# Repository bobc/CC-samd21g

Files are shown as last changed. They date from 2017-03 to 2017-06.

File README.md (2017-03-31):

CC-samd21g Breakout Board
========================================

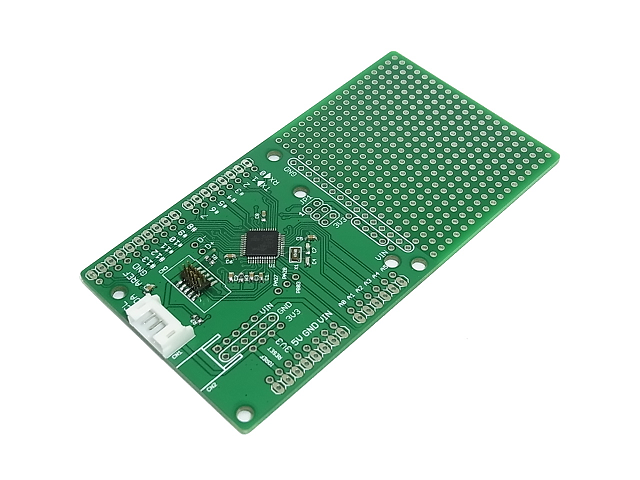
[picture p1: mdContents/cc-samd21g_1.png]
CC-SAMD21 Breakout
  
The CC-SAMD21 Breakout Board is breakout for the Atmel ATSAMD21G18 with prototyping area.  
This board shape is dirfferent from Arduino UNO or Zero, but it has Arduino Uno V3 style headers.  
There are only the minimal set of parts for running microcontroller. When you make your own circuit boards, this board might be helpful.

### Some highlights of the CC-samd21g Breakout Board:
 1. Main core: [ATSAMD21G18](http://www.atmel.com/devices/ATSAMD21G18A.aspx)
 2. Volatage regulator can be mounted in the extra prototyping area.
 3. Prototyping area 43.94mm(1730mil) x 53.34mm(2100mil)
 4. Measures 99.82mm(3930mil) x 53.34mm(2100mil)

Repository Contents
-------------------
* **/Hardware** - All Eagle design files (.brd, .sch)
* **/Software** - Software files for this hardware

Description(Pin Interfaces)
-------------------
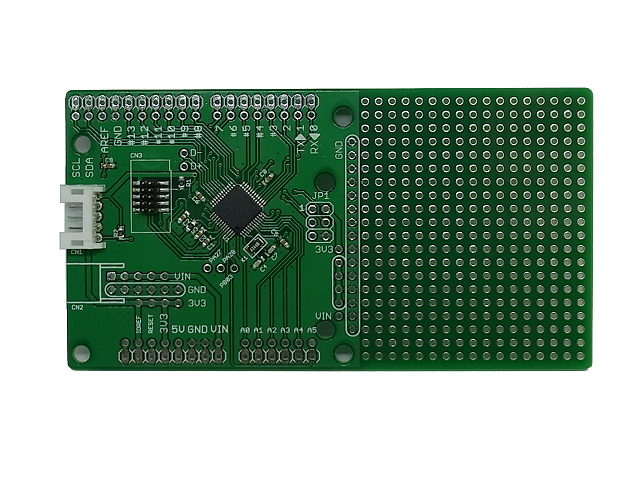
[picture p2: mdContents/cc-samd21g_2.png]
TopView


### CN1 Pin Descriptions:
This connector is for Flashing a program microcontroller.
If you change BOOT MODE, To be selected BOOT MODE before connecting the power supply.  
And also, Communicate with SMA21G using "Serial" function.
- **VCC:** Restrictly 3.3VDC.
- **TX:** PB22 used as UART TX.
- **RX:** PB23 used as UART RX.
- **GND:** GND.
- **BOOT MODE:** Connected to "PA13" H:Flash boot(normally) L:UART download

If you are interested in more useful uart module, please see the [General Serial Communication Board](https://github.com/NaoNaoMe/General-Serial-Communication-Board).

### CN2 Pin Descriptions:
This connector is as power supply.
You can mount a voltage regulator in the extra prototyping area near the connector.
- **VIN:** Depending on the voltage regulator requirements.
- **GND:** GND.

How to burn bootloader and upload sketch
-------------------
See [this page](BurnBootloader.md)

License
-------------------
The repository is released under [Creative Commons ShareAlike 4.0 International](https://creativecommons.org/licenses/by-sa/4.0/).

Distributed as-is; no warranty is given.

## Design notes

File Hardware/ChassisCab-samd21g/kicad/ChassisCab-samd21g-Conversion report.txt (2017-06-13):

info: Conversion report on 2017-06-13 19:33:48
info: 
info: Parameters:
info: Input  : C:\git_bobc\CC-samd21g\Hardware\ChassisCab-samd21g\ChassisCab-samd21g.brd
info: Output : C:\git_bobc\CC-samd21g\Hardware\ChassisCab-samd21g\kicad
info: 
info: Log:
info: Reading board file C:\git_bobc\CC-samd21g\Hardware\ChassisCab-samd21g\ChassisCab-samd21g.brd
info: Processing Library: arduino
info: Processing Library: jst
info: Processing Library: atmel
info: Processing Library: samtec
info: Processing Library: epson
info: Processing Library: rcl
info: Processing Library: Misc
warning: unsupported layer: 214 214bmp in 
warning: unsupported layer: 19 Unrouted in 
note: loose via converted to pad at 35.052,18.796 net=GND
note: loose via converted to pad at 25.4,22.86 net=GND
note: loose via converted to pad at 23.876,24.384 net=GND
note: loose via converted to pad at 21.336,26.924 net=GND
note: loose via converted to pad at 35.56,3.81 net=GND
note: loose via converted to pad at 38.1,3.81 net=GND
note: loose via converted to pad at 40.64,3.81 net=GND
note: loose via converted to pad at 43.18,3.81 net=GND
note: loose via converted to pad at 38.1,16.002 net=GND
note: loose via converted to pad at 40.64,17.78 net=GND
note: loose via converted to pad at 43.18,19.558 net=GND
note: loose via converted to pad at 40.64,41.148 net=GND
note: loose via converted to pad at 34.036,39.116 net=GND
note: loose via converted to pad at 33.02,42.164 net=GND
note: loose via converted to pad at 21.336,39.878 net=GND
note: loose via converted to pad at 11.176,38.862 net=GND
note: loose via converted to pad at 12.7,3.81 net=GND
note: loose via converted to pad at 15.24,3.81 net=GND
note: loose via converted to pad at 8.89,31.242 net=GND
note: loose via converted to pad at 3.302,27.686 net=GND
note: loose via converted to pad at 3.302,26.67 net=GND
note: loose via converted to pad at 10.414,32.766 net=GND
note: loose via converted to pad at 25.146,35.306 net=GND
note: loose via converted to pad at 32.004,23.876 net=GND
note: loose via converted to pad at 33.02,3.81 net=GND
note: loose via converted to pad at 43.434,29.972 net=GND
note: loose via converted to pad at 28.448,18.034 net=GND
note: loose via converted to pad at 10.414,23.622 net=GND
note: loose via converted to pad at 10.414,21.082 net=GND
note: loose via converted to pad at 5.842,15.24 net=GND
note: loose via converted to pad at 5.842,5.842 net=GND
note: loose via converted to pad at 10.414,9.398 net=GND
note: loose via converted to pad at 10.414,10.922 net=GND
note: loose via converted to pad at 11.938,10.922 net=GND
note: loose via converted to pad at 11.938,9.398 net=GND
note: loose via converted to pad at 3.556,49.53 net=GND
note: loose via converted to pad at 38.1,49.53 net=GND
note: loose via converted to pad at 27.178,50.8 net=GND
note: loose via converted to pad at 37.592,39.37 net=GND
note: loose via converted to pad at 3.302,36.322 net=GND
note: loose via converted to pad at 3.302,10.922 net=GND
note: loose via converted to pad at 12.446,48.26 net=SCK
note: loose via converted to pad at 52.07,22.86 net=+3V3
note: loose via converted to pad at 19.05,5.08 net=+3V3
note: loose via converted to pad at 13.97,12.7 net=+3V3
note: loose via converted to pad at 16.51,12.7 net=+3V3
note: loose via converted to pad at 19.05,12.7 net=+3V3
note: loose via converted to pad at 21.59,12.7 net=+3V3
note: loose via converted to pad at 13.97,5.08 net=+3V3
note: loose via converted to pad at 14.986,48.26 net=MISO
note: loose via converted to pad at 17.526,48.26 net=MOSI
note: loose via converted to pad at 20.066,48.26 net=SS
note: loose via converted to pad at 34.29,5.08 net=PA02_AIN0
note: loose via converted to pad at 7.366,48.26 net=PA03_AREFA
note: loose via converted to pad at 36.83,5.08 net=PB08_AIN2
note: loose via converted to pad at 39.37,5.08 net=PB09_AIN3
note: loose via converted to pad at 41.91,5.08 net=PA04_AIN4
note: loose via converted to pad at 44.45,5.08 net=PA05_AIN5
note: loose via converted to pad at 39.37,48.26 net=PA09_TCC0-W1
note: loose via converted to pad at 44.45,48.26 net=PA10_TCC0-W2
note: loose via converted to pad at 46.99,48.26 net=PA11_TCC0-W3
note: loose via converted to pad at 34.29,48.26 net=PA15_TCC0-W5
note: loose via converted to pad at 31.75,48.26 net=PA20_TCC0-W6
note: loose via converted to pad at 46.99,5.08 net=PB02_AIN10
note: loose via converted to pad at 29.21,48.26 net=PA21
note: loose via converted to pad at 22.606,48.26 net=PA07
note: loose via converted to pad at 4.826,48.26 net=SDA
note: loose via converted to pad at 2.286,48.26 net=SCL
note: loose via converted to pad at 16.51,5.08 net=SAMD21_RESET
note: loose via converted to pad at 41.91,48.26 net=PA08_TCC0-W0
note: loose via converted to pad at 36.83,48.26 net=PA14_TCC0-W4
note: loose via converted to pad at 25.146,48.26 net=PA06
note: loose via converted to pad at 11.43,17.78 net=VIN
note: loose via converted to pad at 13.97,17.78 net=VIN
note: loose via converted to pad at 16.51,17.78 net=VIN
note: loose via converted to pad at 19.05,17.78 net=VIN
note: loose via converted to pad at 52.07,10.16 net=VIN
note: loose via converted to pad at 29.21,5.08 net=VIN
note: loose via converted to pad at 52.07,20.32 net=N$900
note: loose via converted to pad at 52.07,17.78 net=N$900
note: loose via converted to pad at 52.07,15.24 net=N$900
note: loose via converted to pad at 52.07,12.7 net=N$900
note: loose via converted to pad at 57.15,50.8 net=N$3
note: loose via converted to pad at 57.15,48.26 net=N$4
note: loose via converted to pad at 57.15,45.72 net=N$5
note: loose via converted to pad at 57.15,43.18 net=N$6
note: loose via converted to pad at 57.15,40.64 net=N$7
note: loose via converted to pad at 57.15,38.1 net=N$8
note: loose via converted to pad at 57.15,35.56 net=N$9
note: loose via converted to pad at 57.15,33.02 net=N$10
note: loose via converted to pad at 57.15,30.48 net=N$11
note: loose via converted to pad at 57.15,27.94 net=N$12
note: loose via converted to pad at 57.15,25.4 net=N$13
note: loose via converted to pad at 57.15,22.86 net=N$14
note: loose via converted to pad at 57.15,20.32 net=N$15
note: loose via converted to pad at 57.15,17.78 net=N$16
note: loose via converted to pad at 57.15,15.24 net=N$17
note: loose via converted to pad at 57.15,12.7 net=N$18
note: loose via converted to pad at 57.15,10.16 net=N$19
note: loose via converted to pad at 57.15,7.62 net=N$20
note: loose via converted to pad at 57.15,5.08 net=N$21
note: loose via converted to pad at 57.15,2.54 net=N$22
note: loose via converted to pad at 59.69,50.8 net=N$23
note: loose via converted to pad at 59.69,48.26 net=N$24
note: loose via converted to pad at 59.69,45.72 net=N$25
note: loose via converted to pad at 59.69,43.18 net=N$26
note: loose via converted to pad at 59.69,40.64 net=N$27
note: loose via converted to pad at 59.69,38.1 net=N$28
note: loose via converted to pad at 59.69,35.56 net=N$29
note: loose via converted to pad at 59.69,33.02 net=N$30
note: loose via converted to pad at 59.69,30.48 net=N$31
note: loose via converted to pad at 59.69,27.94 net=N$32
note: loose via converted to pad at 59.69,25.4 net=N$33
note: loose via converted to pad at 59.69,22.86 net=N$34
note: loose via converted to pad at 59.69,20.32 net=N$35
note: loose via converted to pad at 59.69,17.78 net=N$36
note: loose via converted to pad at 59.69,15.24 net=N$37
note: loose via converted to pad at 59.69,12.7 net=N$38
note: loose via converted to pad at 59.69,10.16 net=N$39
note: loose via converted to pad at 59.69,7.62 net=N$40
note: loose via converted to pad at 59.69,5.08 net=N$41
note: loose via converted to pad at 59.69,2.54 net=N$42
note: loose via converted to pad at 62.23,50.8 net=N$43
note: loose via converted to pad at 62.23,48.26 net=N$44
note: loose via converted to pad at 62.23,45.72 net=N$45
note: loose via converted to pad at 62.23,43.18 net=N$46
note: loose via converted to pad at 62.23,40.64 net=N$47
note: loose via converted to pad at 62.23,38.1 net=N$48
note: loose via converted to pad at 62.23,35.56 net=N$49
note: loose via converted to pad at 62.23,33.02 net=N$50
note: loose via converted to pad at 62.23,30.48 net=N$51
note: loose via converted to pad at 62.23,27.94 net=N$52
note: loose via converted to pad at 62.23,25.4 net=N$53
note: loose via converted to pad at 62.23,22.86 net=N$54
note: loose via converted to pad at 62.23,20.32 net=N$55
note: loose via converted to pad at 62.23,17.78 net=N$56
note: loose via converted to pad at 62.23,15.24 net=N$57
note: loose via converted to pad at 62.23,12.7 net=N$58
note: loose via converted to pad at 62.23,10.16 net=N$59
note: loose via converted to pad at 62.23,7.62 net=N$60
note: loose via converted to pad at 62.23,5.08 net=N$61
note: loose via converted to pad at 62.23,2.54 net=N$62
note: loose via converted to pad at 64.77,50.8 net=N$63
note: loose via converted to pad at 64.77,48.26 net=N$64
note: loose via converted to pad at 64.77,45.72 net=N$65
note: loose via converted to pad at 64.77,43.18 net=N$66
note: loose via converted to pad at 64.77,40.64 net=N$67
note: loose via converted to pad at 64.77,38.1 net=N$68
note: loose via converted to pad at 64.77,35.56 net=N$69
note: loose via converted to pad at 64.77,33.02 net=N$70
note: loose via converted to pad at 64.77,30.48 net=N$71
note: loose via converted to pad at 64.77,27.94 net=N$72
note: loose via converted to pad at 64.77,25.4 net=N$73
note: loose via converted to pad at 64.77,22.86 net=N$74
note: loose via converted to pad at 64.77,20.32 net=N$75
note: loose via converted to pad at 64.77,17.78 net=N$76
note: loose via converted to pad at 64.77,15.24 net=N$77
note: loose via converted to pad at 64.77,12.7 net=N$78
note: loose via converted to pad at 64.77,10.16 net=N$79
note: loose via converted to pad at 64.77,7.62 net=N$80
note: loose via converted to pad at 64.77,5.08 net=N$81
note: loose via converted to pad at 64.77,2.54 net=N$82
note: loose via converted to pad at 67.31,50.8 net=N$83
note: loose via converted to pad at 67.31,48.26 net=N$84
note: loose via converted to pad at 67.31,45.72 net=N$85
note: loose via converted to pad at 67.31,43.18 net=N$86
note: loose via converted to pad at 67.31,40.64 net=N$87
note: loose via converted to pad at 67.31,38.1 net=N$88
note: loose via converted to pad at 67.31,35.56 net=N$89
note: loose via converted to pad at 67.31,33.02 net=N$90
note: loose via converted to pad at 67.31,30.48 net=N$91
note: loose via converted to pad at 67.31,27.94 net=N$92
note: loose via converted to pad at 67.31,25.4 net=N$93
note: loose via converted to pad at 67.31,22.86 net=N$94
note: loose via converted to pad at 67.31,20.32 net=N$95
note: loose via converted to pad at 67.31,17.78 net=N$96
note: loose via converted to pad at 67.31,15.24 net=N$97
note: loose via converted to pad at 67.31,12.7 net=N$98
note: loose via converted to pad at 67.31,10.16 net=N$99
note: loose via converted to pad at 67.31,7.62 net=N$100
note: loose via converted to pad at 67.31,5.08 net=N$101
note: loose via converted to pad at 67.31,2.54 net=N$102
note: loose via converted to pad at 69.85,50.8 net=N$103
note: loose via converted to pad at 69.85,48.26 net=N$104
note: loose via converted to pad at 69.85,45.72 net=N$105
note: loose via converted to pad at 69.85,43.18 net=N$106
note: loose via converted to pad at 69.85,40.64 net=N$107
note: loose via converted to pad at 69.85,38.1 net=N$108
note: loose via converted to pad at 69.85,35.56 net=N$109
note: loose via converted to pad at 69.85,33.02 net=N$110
note: loose via converted to pad at 69.85,30.48 net=N$111
note: loose via converted to pad at 69.85,27.94 net=N$112
note: loose via converted to pad at 69.85,25.4 net=N$113
note: loose via converted to pad at 69.85,22.86 net=N$114
note: loose via converted to pad at 69.85,20.32 net=N$115
note: loose via converted to pad at 69.85,17.78 net=N$116
note: loose via converted to pad at 69.85,15.24 net=N$117
note: loose via converted to pad at 69.85,12.7 net=N$118
note: loose via converted to pad at 69.85,10.16 net=N$119
note: loose via converted to pad at 69.85,7.62 net=N$120
note: loose via converted to pad at 69.85,5.08 net=N$121
note: loose via converted to pad at 69.85,2.54 net=N$122
note: loose via converted to pad at 72.39,50.8 net=N$123
note: loose via converted to pad at 72.39,48.26 net=N$124
note: loose via converted to pad at 72.39,45.72 net=N$125
note: loose via converted to pad at 72.39,43.18 net=N$126
note: loose via converted to pad at 72.39,40.64 net=N$127
note: loose via converted to pad at 72.39,38.1 net=N$128
note: loose via converted to pad at 72.39,35.56 net=N$129
note: loose via converted to pad at 72.39,33.02 net=N$130
note: loose via converted to pad at 72.39,30.48 net=N$131
note: loose via converted to pad at 72.39,27.94 net=N$132
note: loose via converted to pad at 72.39,25.4 net=N$133
note: loose via converted to pad at 72.39,22.86 net=N$134
note: loose via converted to pad at 72.39,20.32 net=N$135
note: loose via converted to pad at 72.39,17.78 net=N$136
note: loose via converted to pad at 72.39,15.24 net=N$137
note: loose via converted to pad at 72.39,12.7 net=N$138
note: loose via converted to pad at 72.39,10.16 net=N$139
note: loose via converted to pad at 72.39,7.62 net=N$140
note: loose via converted to pad at 72.39,5.08 net=N$141
note: loose via converted to pad at 72.39,2.54 net=N$142
note: loose via converted to pad at 74.93,50.8 net=N$143
note: loose via converted to pad at 74.93,48.26 net=N$144
note: loose via converted to pad at 74.93,45.72 net=N$145
note: loose via converted to pad at 74.93,43.18 net=N$146
note: loose via converted to pad at 74.93,40.64 net=N$147
note: loose via converted to pad at 74.93,38.1 net=N$148
note: loose via converted to pad at 74.93,35.56 net=N$149
note: loose via converted to pad at 74.93,33.02 net=N$150
note: loose via converted to pad at 74.93,30.48 net=N$151
note: loose via converted to pad at 74.93,27.94 net=N$152
note: loose via converted to pad at 74.93,25.4 net=N$153
note: loose via converted to pad at 74.93,22.86 net=N$154
note: loose via converted to pad at 74.93,20.32 net=N$155
note: loose via converted to pad at 74.93,17.78 net=N$156
note: loose via converted to pad at 74.93,15.24 net=N$157
note: loose via converted to pad at 74.93,12.7 net=N$158
note: loose via converted to pad at 74.93,10.16 net=N$159
note: loose via converted to pad at 74.93,7.62 net=N$160
note: loose via converted to pad at 74.93,5.08 net=N$161
note: loose via converted to pad at 74.93,2.54 net=N$162
note: loose via converted to pad at 77.47,50.8 net=N$163
note: loose via converted to pad at 77.47,48.26 net=N$164
note: loose via converted to pad at 77.47,45.72 net=N$165
note: loose via converted to pad at 77.47,43.18 net=N$166
note: loose via converted to pad at 77.47,40.64 net=N$167
note: loose via converted to pad at 77.47,38.1 net=N$168
note: loose via converted to pad at 77.47,35.56 net=N$169
note: loose via converted to pad at 77.47,33.02 net=N$170
note: loose via converted to pad at 77.47,30.48 net=N$171
note: loose via converted to pad at 77.47,27.94 net=N$172
note: loose via converted to pad at 77.47,25.4 net=N$173
note: loose via converted to pad at 77.47,22.86 net=N$174
note: loose via converted to pad at 77.47,20.32 net=N$175
note: loose via converted to pad at 77.47,17.78 net=N$176
note: loose via converted to pad at 77.47,15.24 net=N$177
note: loose via converted to pad at 77.47,12.7 net=N$178
note: loose via converted to pad at 77.47,10.16 net=N$179
note: loose via converted to pad at 77.47,7.62 net=N$180
note: loose via converted to pad at 77.47,5.08 net=N$181
note: loose via converted to pad at 77.47,2.54 net=N$182
note: loose via converted to pad at 80.01,50.8 net=N$183
note: loose via converted to pad at 80.01,48.26 net=N$184
note: loose via converted to pad at 80.01,45.72 net=N$185
note: loose via converted to pad at 80.01,43.18 net=N$186
note: loose via converted to pad at 80.01,40.64 net=N$187
note: loose via converted to pad at 80.01,38.1 net=N$188
note: loose via converted to pad at 80.01,35.56 net=N$189
note: loose via converted to pad at 80.01,33.02 net=N$190
note: loose via converted to pad at 80.01,30.48 net=N$191
note: loose via converted to pad at 80.01,27.94 net=N$192
note: loose via converted to pad at 80.01,25.4 net=N$193
note: loose via converted to pad at 80.01,22.86 net=N$194
note: loose via converted to pad at 80.01,20.32 net=N$195
note: loose via converted to pad at 80.01,17.78 net=N$196
note: loose via converted to pad at 80.01,15.24 net=N$197
note: loose via converted to pad at 80.01,12.7 net=N$198
note: loose via converted to pad at 80.01,10.16 net=N$199
note: loose via converted to pad at 80.01,7.62 net=N$200
note: loose via converted to pad at 80.01,5.08 net=N$201
note: loose via converted to pad at 80.01,2.54 net=N$202
note: loose via converted to pad at 82.55,50.8 net=N$203
note: loose via converted to pad at 82.55,48.26 net=N$204
note: loose via converted to pad at 82.55,45.72 net=N$205
note: loose via converted to pad at 82.55,43.18 net=N$206
note: loose via converted to pad at 82.55,40.64 net=N$207
note: loose via converted to pad at 82.55,38.1 net=N$208
note: loose via converted to pad at 82.55,35.56 net=N$209
note: loose via converted to pad at 82.55,33.02 net=N$210
note: loose via converted to pad at 82.55,30.48 net=N$211
note: loose via converted to pad at 82.55,27.94 net=N$212
note: loose via converted to pad at 82.55,25.4 net=N$213
note: loose via converted to pad at 82.55,22.86 net=N$214
note: loose via converted to pad at 82.55,20.32 net=N$215
note: loose via converted to pad at 82.55,17.78 net=N$216
note: loose via converted to pad at 82.55,15.24 net=N$217
note: loose via converted to pad at 82.55,12.7 net=N$218
note: loose via converted to pad at 82.55,10.16 net=N$219
note: loose via converted to pad at 82.55,7.62 net=N$220
note: loose via converted to pad at 82.55,5.08 net=N$221
note: loose via converted to pad at 82.55,2.54 net=N$222
note: loose via converted to pad at 85.09,50.8 net=N$223
note: loose via converted to pad at 85.09,48.26 net=N$224
note: loose via converted to pad at 85.09,45.72 net=N$225
note: loose via converted to pad at 85.09,43.18 net=N$226
note: loose via converted to pad at 85.09,40.64 net=N$227
note: loose via converted to pad at 85.09,38.1 net=N$228
note: loose via converted to pad at 85.09,35.56 net=N$229
note: loose via converted to pad at 85.09,33.02 net=N$230
note: loose via converted to pad at 85.09,30.48 net=N$231
note: loose via converted to pad at 85.09,27.94 net=N$232
note: loose via converted to pad at 85.09,25.4 net=N$233
note: loose via converted to pad at 85.09,22.86 net=N$234
note: loose via converted to pad at 85.09,20.32 net=N$235
note: loose via converted to pad at 85.09,17.78 net=N$236
note: loose via converted to pad at 85.09,15.24 net=N$237
note: loose via converted to pad at 85.09,12.7 net=N$238
note: loose via converted to pad at 85.09,10.16 net=N$239
note: loose via converted to pad at 85.09,7.62 net=N$240
note: loose via converted to pad at 85.09,5.08 net=N$241
note: loose via converted to pad at 85.09,2.54 net=N$242
note: loose via converted to pad at 87.63,50.8 net=N$243
note: loose via converted to pad at 87.63,48.26 net=N$244
note: loose via converted to pad at 87.63,45.72 net=N$245
note: loose via converted to pad at 87.63,43.18 net=N$246
note: loose via converted to pad at 87.63,40.64 net=N$247
note: loose via converted to pad at 87.63,38.1 net=N$248
note: loose via converted to pad at 87.63,35.56 net=N$249
note: loose via converted to pad at 87.63,33.02 net=N$250
note: loose via converted to pad at 87.63,30.48 net=N$251
note: loose via converted to pad at 87.63,27.94 net=N$252
note: loose via converted to pad at 87.63,25.4 net=N$253
note: loose via converted to pad at 87.63,22.86 net=N$254
note: loose via converted to pad at 87.63,20.32 net=N$255
note: loose via converted to pad at 87.63,17.78 net=N$256
note: loose via converted to pad at 87.63,15.24 net=N$257
note: loose via converted to pad at 87.63,12.7 net=N$258
note: loose via converted to pad at 87.63,10.16 net=N$259
note: loose via converted to pad at 87.63,7.62 net=N$260
note: loose via converted to pad at 87.63,5.08 net=N$261
note: loose via converted to pad at 87.63,2.54 net=N$262
note: loose via converted to pad at 90.17,50.8 net=N$263
note: loose via converted to pad at 90.17,48.26 net=N$264
note: loose via converted to pad at 90.17,45.72 net=N$265
note: loose via converted to pad at 90.17,43.18 net=N$266
note: loose via converted to pad at 90.17,40.64 net=N$267
note: loose via converted to pad at 90.17,38.1 net=N$268
note: loose via converted to pad at 90.17,35.56 net=N$269
note: loose via converted to pad at 90.17,33.02 net=N$270
note: loose via converted to pad at 90.17,30.48 net=N$271
note: loose via converted to pad at 90.17,27.94 net=N$272
note: loose via converted to pad at 90.17,25.4 net=N$273
note: loose via converted to pad at 90.17,22.86 net=N$274
note: loose via converted to pad at 90.17,20.32 net=N$275
note: loose via converted to pad at 90.17,17.78 net=N$276
note: loose via converted to pad at 90.17,15.24 net=N$277
note: loose via converted to pad at 90.17,12.7 net=N$278
note: loose via converted to pad at 90.17,10.16 net=N$279
note: loose via converted to pad at 90.17,7.62 net=N$280
note: loose via converted to pad at 90.17,5.08 net=N$281
note: loose via converted to pad at 90.17,2.54 net=N$282
note: loose via converted to pad at 92.71,50.8 net=N$283
note: loose via converted to pad at 92.71,48.26 net=N$284
note: loose via converted to pad at 92.71,45.72 net=N$285
note: loose via converted to pad at 92.71,43.18 net=N$286
note: loose via converted to pad at 92.71,40.64 net=N$287
note: loose via converted to pad at 92.71,38.1 net=N$288
note: loose via converted to pad at 92.71,35.56 net=N$289
note: loose via converted to pad at 92.71,33.02 net=N$290
note: loose via converted to pad at 92.71,30.48 net=N$291
note: loose via converted to pad at 92.71,27.94 net=N$292
note: loose via converted to pad at 92.71,25.4 net=N$293
note: loose via converted to pad at 92.71,22.86 net=N$294
note: loose via converted to pad at 92.71,20.32 net=N$295
note: loose via converted to pad at 92.71,17.78 net=N$296
note: loose via converted to pad at 92.71,15.24 net=N$297
note: loose via converted to pad at 92.71,12.7 net=N$298
note: loose via converted to pad at 92.71,10.16 net=N$299
note: loose via converted to pad at 92.71,7.62 net=N$300
note: loose via converted to pad at 92.71,5.08 net=N$301
note: loose via converted to pad at 92.71,2.54 net=N$302
note: loose via converted to pad at 95.25,50.8 net=N$303
note: loose via converted to pad at 95.25,48.26 net=N$304
note: loose via converted to pad at 95.25,45.72 net=N$305
note: loose via converted to pad at 95.25,43.18 net=N$306
note: loose via converted to pad at 95.25,40.64 net=N$307
note: loose via converted to pad at 95.25,38.1 net=N$308
note: loose via converted to pad at 95.25,35.56 net=N$309
note: loose via converted to pad at 95.25,33.02 net=N$310
note: loose via converted to pad at 95.25,30.48 net=N$311
note: loose via converted to pad at 95.25,27.94 net=N$312
note: loose via converted to pad at 95.25,25.4 net=N$313
note: loose via converted to pad at 95.25,22.86 net=N$314
note: loose via converted to pad at 95.25,20.32 net=N$315
note: loose via converted to pad at 95.25,17.78 net=N$316
note: loose via converted to pad at 95.25,15.24 net=N$317
note: loose via converted to pad at 95.25,12.7 net=N$318
note: loose via converted to pad at 95.25,10.16 net=N$319
note: loose via converted to pad at 95.25,7.62 net=N$320
note: loose via converted to pad at 95.25,5.08 net=N$321
note: loose via converted to pad at 95.25,2.54 net=N$322
note: loose via converted to pad at 97.79,50.8 net=N$323
note: loose via converted to pad at 97.79,48.26 net=N$324
note: loose via converted to pad at 97.79,45.72 net=N$325
note: loose via converted to pad at 97.79,43.18 net=N$326
note: loose via converted to pad at 97.79,40.64 net=N$327
note: loose via converted to pad at 97.79,38.1 net=N$328
note: loose via converted to pad at 97.79,35.56 net=N$329
note: loose via converted to pad at 97.79,33.02 net=N$330
note: loose via converted to pad at 97.79,30.48 net=N$331
note: loose via converted to pad at 97.79,27.94 net=N$332
note: loose via converted to pad at 97.79,25.4 net=N$333
note: loose via converted to pad at 97.79,22.86 net=N$334
note: loose via converted to pad at 97.79,20.32 net=N$335
note: loose via converted to pad at 97.79,17.78 net=N$336
note: loose via converted to pad at 97.79,15.24 net=N$337
note: loose via converted to pad at 97.79,12.7 net=N$338
note: loose via converted to pad at 97.79,10.16 net=N$339
note: loose via converted to pad at 97.79,7.62 net=N$340
note: loose via converted to pad at 97.79,5.08 net=N$341
note: loose via converted to pad at 97.79,2.54 net=N$342
info: Writing board C:\git_bobc\CC-samd21g\Hardware\ChassisCab-samd21g\kicad\ChassisCab-samd21g.kicad_pcb
info: Reading schematic file C:\git_bobc\CC-samd21g\Hardware\ChassisCab-samd21g\ChassisCab-samd21g.sch
info: Processing Library: Misc
info: Processing Library: arduino
note: 1X10/90 is renamed to 1X10_90
info: Processing Library: jst
info: Processing Library: atmel
info: Processing Library: samtec
info: Processing Library: epson
info: Processing Library: rcl
note: 0204/5 is renamed to 0204_5
note: 0204/7 is renamed to 0204_7
note: 0207/10 is renamed to 0207_10
note: 0207/12 is renamed to 0207_12
note: 0207/15 is renamed to 0207_15
note: 0207/2V is renamed to 0207_2V
note: 0207/5V is renamed to 0207_5V
note: 0207/7 is renamed to 0207_7
note: 0309/10 is renamed to 0309_10
note: 0309/12 is renamed to 0309_12
note: 0411/12 is renamed to 0411_12
note: 0411/15 is renamed to 0411_15
note: 0414/15 is renamed to 0414_15
note: 0617/17 is renamed to 0617_17
note: 0617/22 is renamed to 0617_22
note: 0922/22 is renamed to 0922_22
note: P0613/15 is renamed to P0613_15
note: P0817/22 is renamed to P0817_22
note: V234/12 is renamed to V234_12
note: V235/17 is renamed to V235_17
note: RDH/15 is renamed to RDH_15
note: WSC01/2 is renamed to WSC01_2
info: Processing Library: supply
info: Processing schematic sheet: 1
note: IOL is renamed IOL1
note: IOH is renamed IOH1
note: AD is renamed AD1
note: POWER is renamed POWER1
info: Writing schematic C:\git_bobc\CC-samd21g\Hardware\ChassisCab-samd21g\kicad\ChassisCab-samd21g.sch
info: Writing project file C:\git_bobc\CC-samd21g\Hardware\ChassisCab-samd21g\kicad\ChassisCab-samd21g.pro
info: 
info: Done
info: *** See report file for 0 errors, 2 warnings, 449 notes ***

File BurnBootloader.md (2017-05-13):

Burn Bootloader and upload a program for CC-samd21g Breakout Board
========================================

First of all
--------------
You will need the following items for this instruction.
 - ATEML-ICE
 - FTDI BREAKOUT BOARD(3.3V)
 - reprogramming cable(you should assebele it.)

Software Setup
--------------
To import the CC-samd21g Breakout Board, add the following text in the 'boards.txt' file, located in the following directory:

```
# CC-SAMD21G (Serial Port)
# ---------------------------------------
cc-samd21g.name=CC-SAMD21G (Serial Port)
cc-samd21g.upload.tool=bossac
cc-samd21g.upload.protocol=sam-ba
cc-samd21g.upload.maximum_size=262144
cc-samd21g.upload.use_1200bps_touch=false
cc-samd21g.upload.wait_for_upload_port=false
cc-samd21g.upload.native_usb=true
cc-samd21g.build.mcu=cortex-m0plus
cc-samd21g.build.f_cpu=48000000L
cc-samd21g.build.usb_product="CC-SAMD21G"
cc-samd21g.build.usb_manufacturer=""
cc-samd21g.build.board=SAMD_ZERO
cc-samd21g.build.core=arduino
cc-samd21g.build.extra_flags=-D__SAMD21G18A__ {build.usb_flags}
cc-samd21g.build.ldscript=linker_scripts/gcc/flash_with_bootloader.ld
cc-samd21g.build.openocdscript=openocd_scripts/arduino_zero.cfg
cc-samd21g.build.variant=arduino_zero
cc-samd21g.build.variant_system_lib=
cc-samd21g.build.vid=0x0000
cc-samd21g.build.pid=0x0000
cc-samd21g.bootloader.tool=openocd
cc-samd21g.bootloader.file=cc/samd21_sam_ba_cc.bin
```

```
* C:\Users\(username)\AppData\Local\Arduino15\packages\arduino\hardware\samd\1.6.xx
```

And store [custom bootloader](Software/bootloader) for this board shown as below.

```
    ^\1.6.xx\bootloaders\cc\samd21_sam_ba_cc.bin
```

Hardware Setup
--------------
Refer to the figure below to make reprogramming cable.  
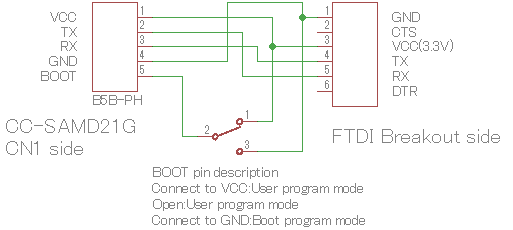
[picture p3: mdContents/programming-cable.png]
CC-SAMD21 cable


### Connection
First you plug ATMEL-ICE SWD cable to CN1.  
ATMEL-ICE Power LED will turn on when you connect FTDI-BOARD with reprogramming cable to CN1.  
If Power LED were not turn on, you should check a cable or connectors certainly plugged.  
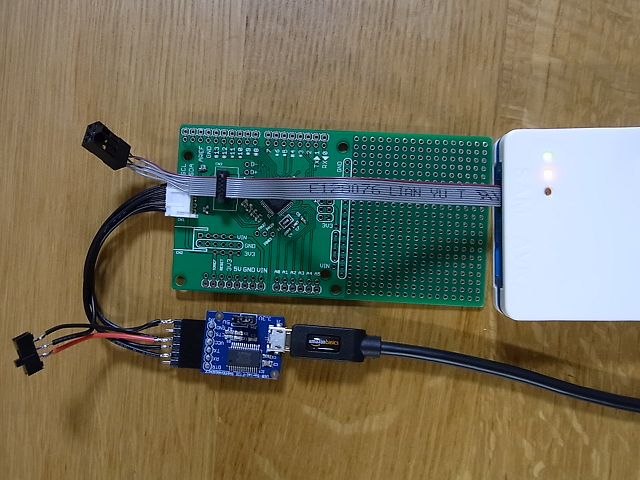
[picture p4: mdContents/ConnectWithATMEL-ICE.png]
CC-SAMD21 with ATMEL-ICE


Burn Bootloader and Upload a program
--------------
### Burn Bootloader
After setting up borads.txt, you can find CC-samd21g board in the Tools > Board menu.  
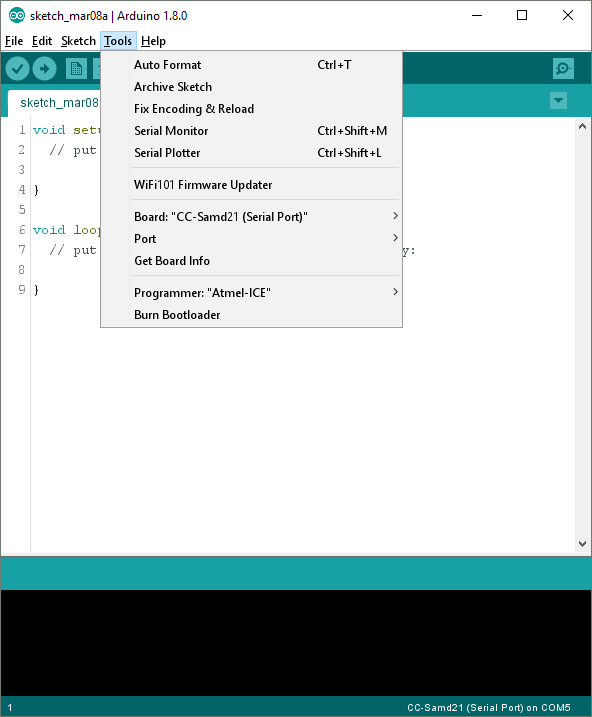
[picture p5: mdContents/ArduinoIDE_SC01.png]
  
Select CC-samd21g and Atmel-ICE as the Tools->Programmer. Then select Burn Bootloader.

### Upload a program
Before you upload your program, please check whether the switch(reprogramming cable) position is tied High(VCC).  
The board allow to control reset pin when EN pin is High.  
Click the Upload button in the IDE. Wait a few seconds. If successful, the message "Done uploading." will appear in the status bar.

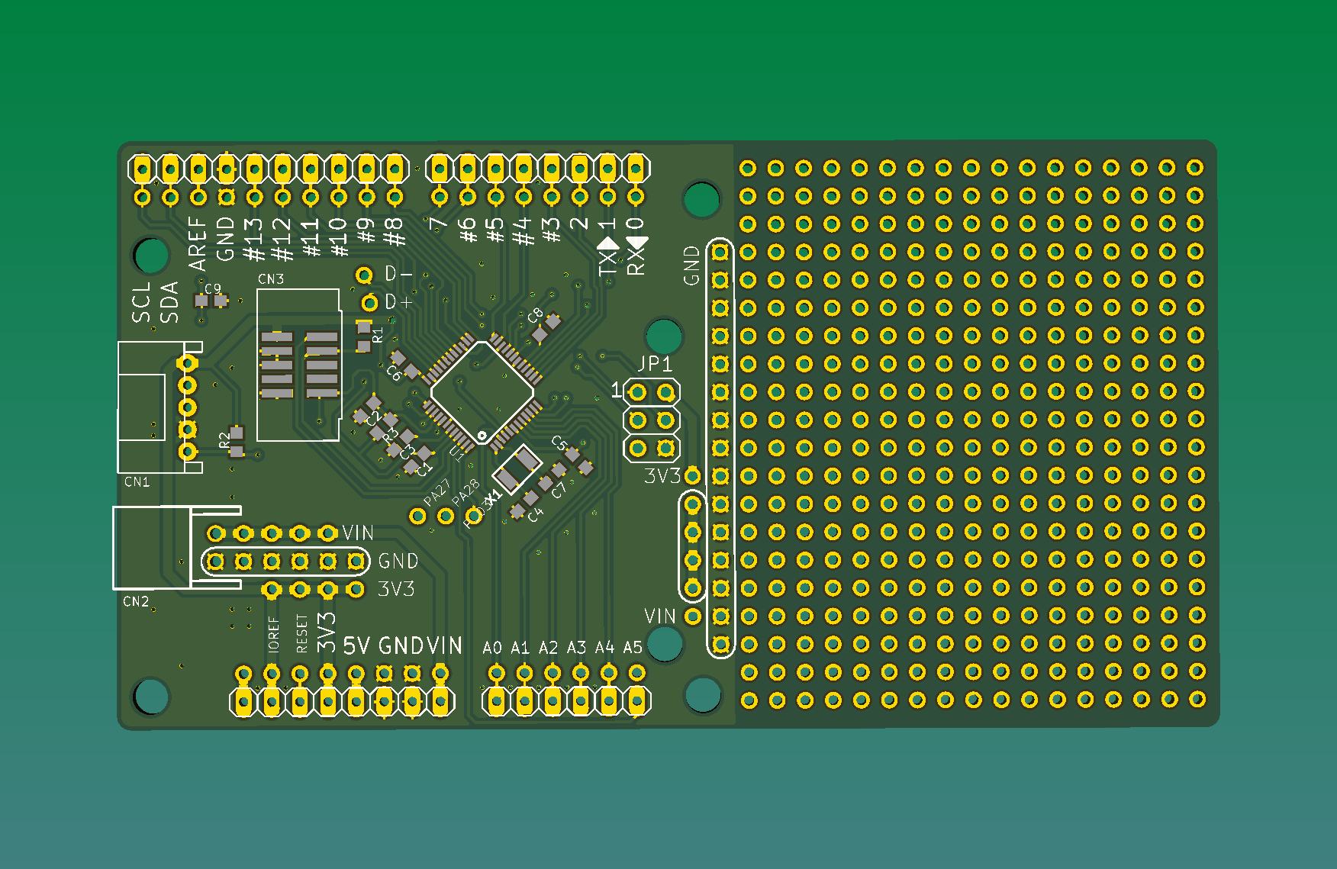
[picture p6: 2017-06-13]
Hardware/ChassisCab-samd21g/kicad/ChassisCab-samd21g.png

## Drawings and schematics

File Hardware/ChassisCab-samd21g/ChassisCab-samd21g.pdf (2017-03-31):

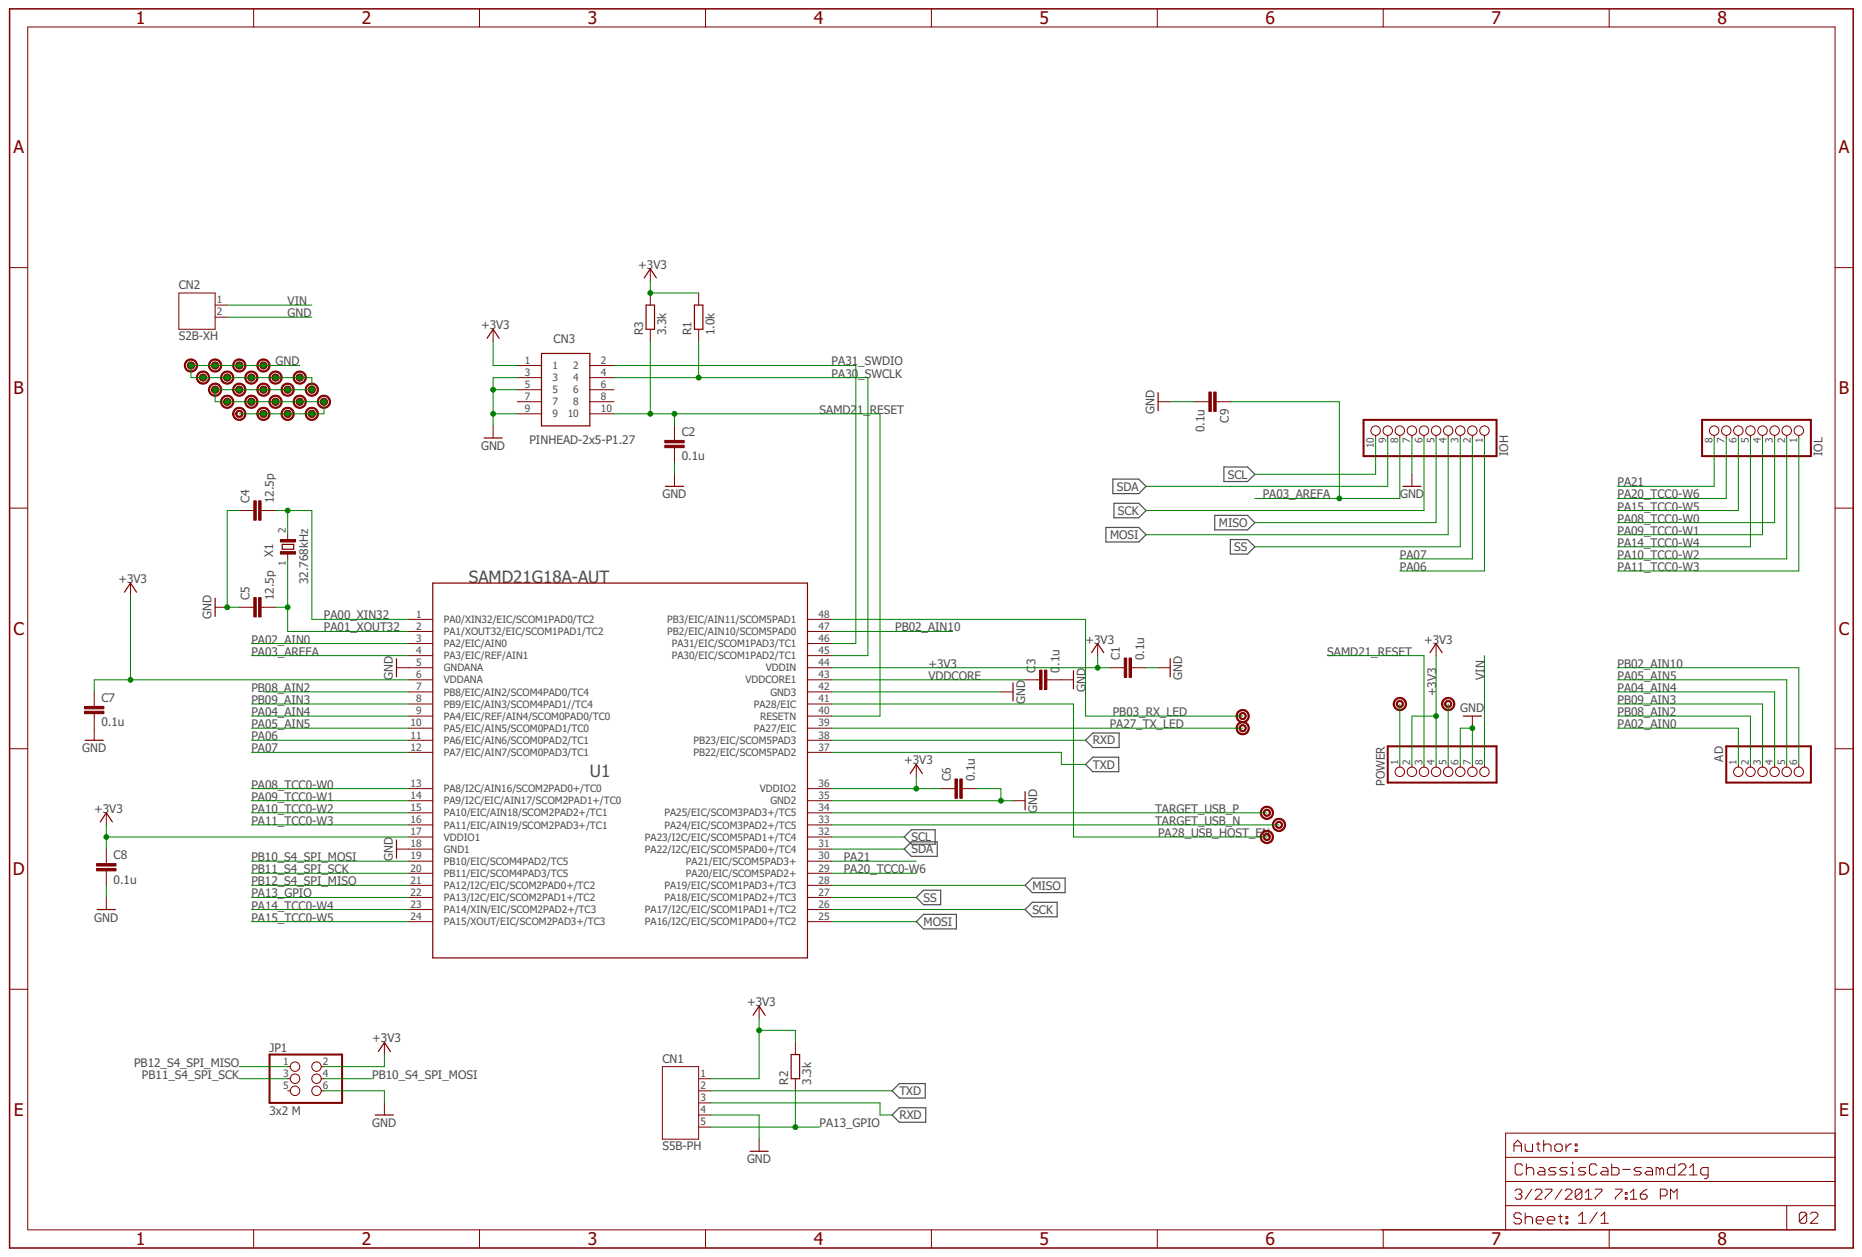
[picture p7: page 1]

41 PA30/EIC/SCOM1PAD2/TC1 43 VDDIN | VDDCORE

PB08_AIN2 +3V3 | | 42

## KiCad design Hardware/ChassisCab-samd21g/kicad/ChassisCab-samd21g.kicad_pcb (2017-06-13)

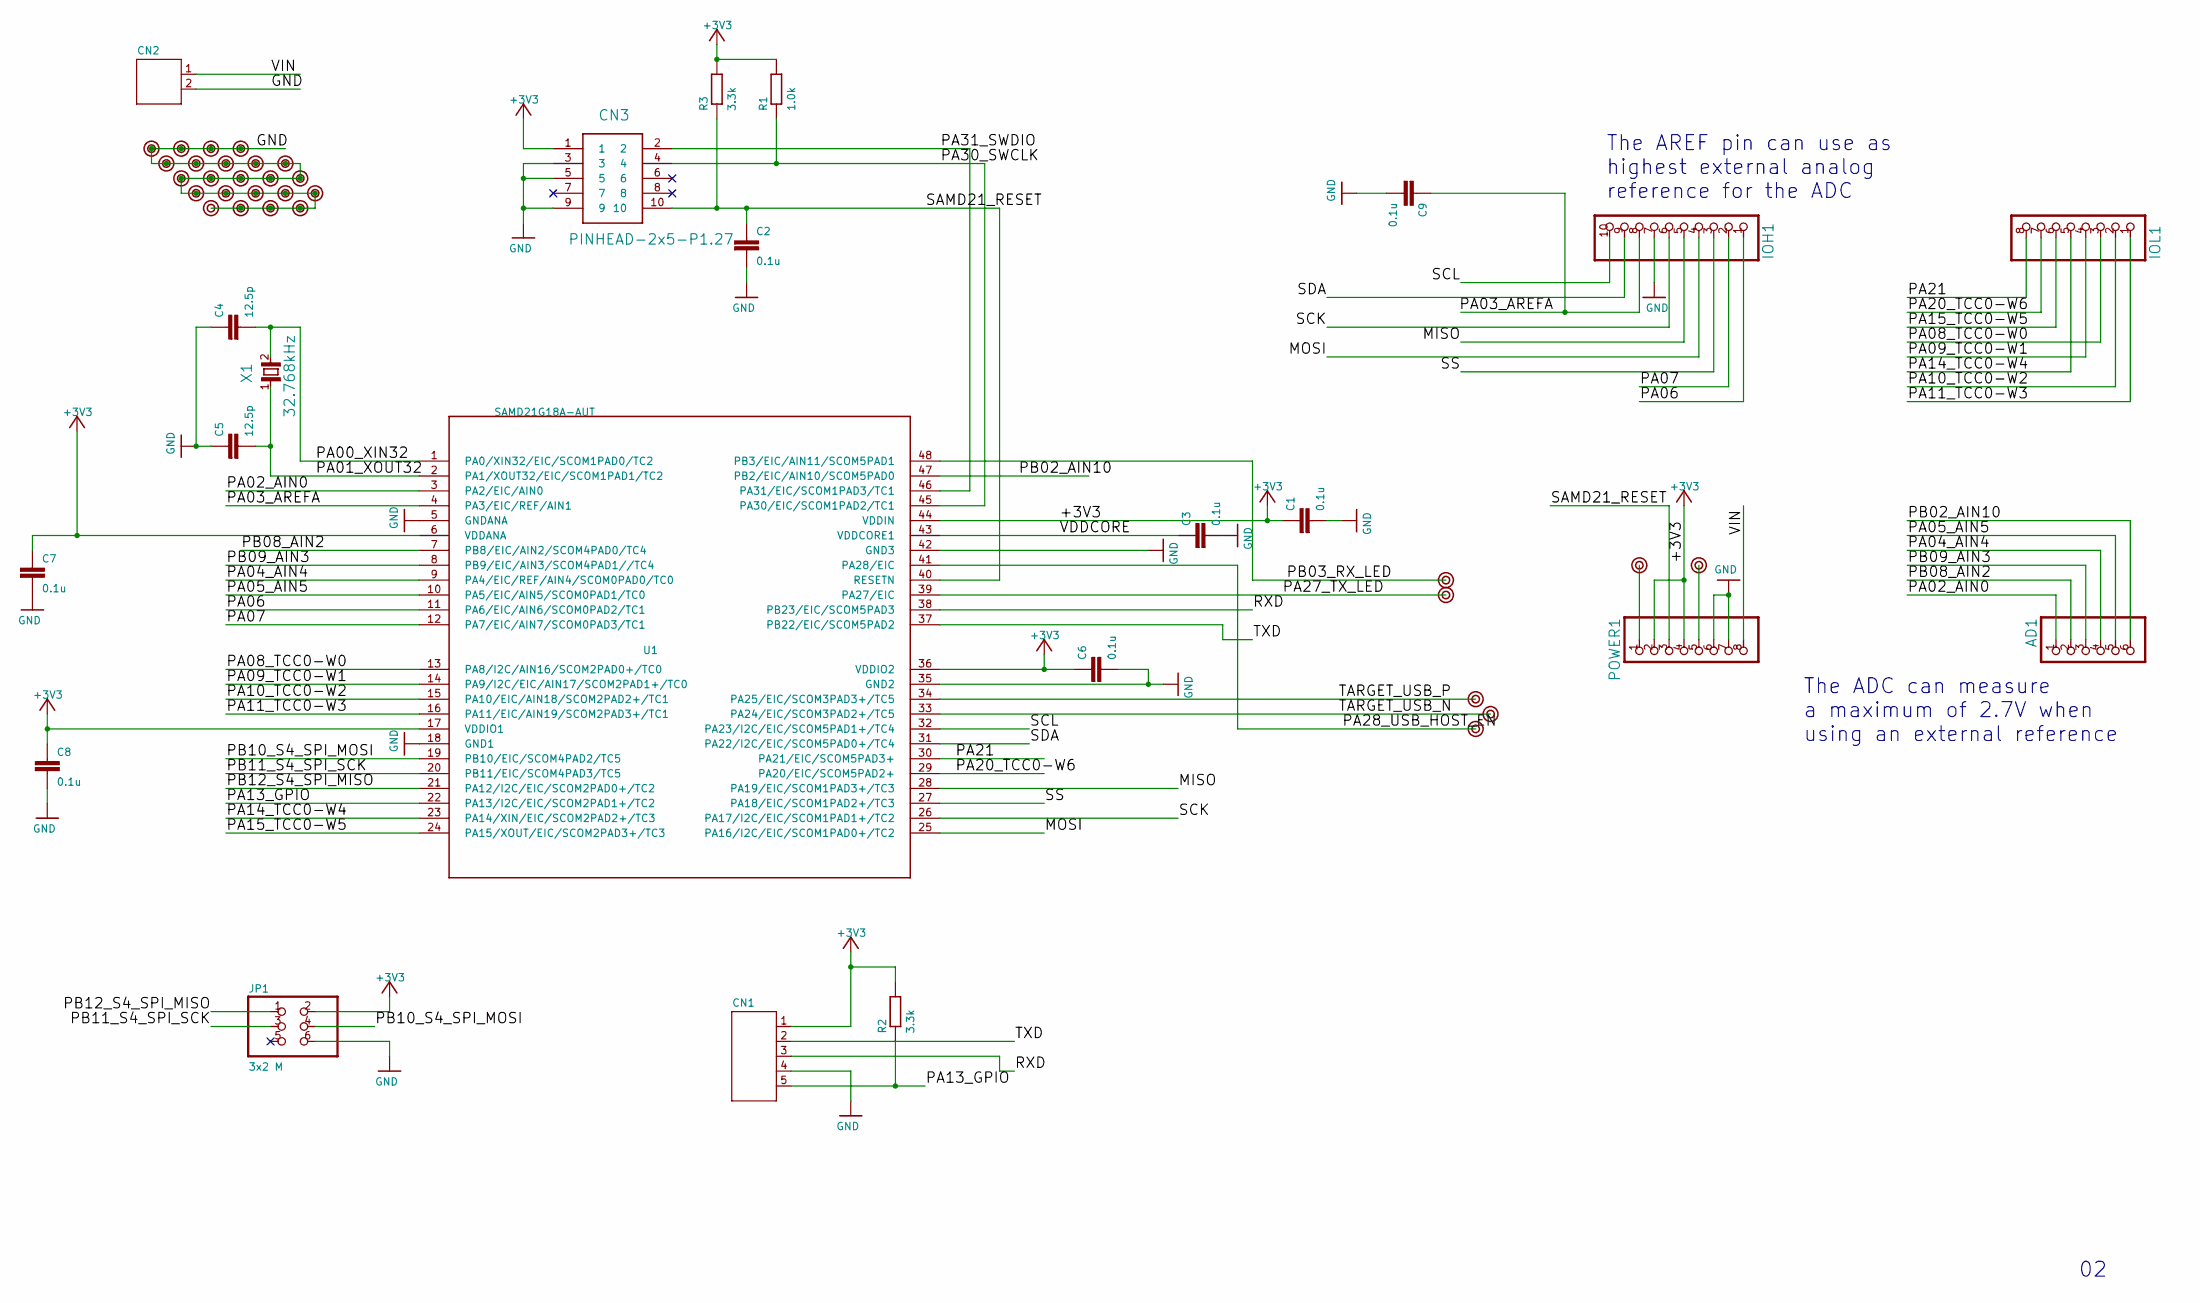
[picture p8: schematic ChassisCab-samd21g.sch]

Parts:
AD1: 6x1F-H8.5; 1X06
C1, C2, C3, C6, C7, C8, C9: 0.1u; C0603
C4, C5: 12.5p; C0603
CN1: S5B-PH
CN2: S2B-XH
CN3: PINHEAD-2x5-P1.27; SHF-105-01-X-D-SM
IOH1: 10x1F-H8.5; 1X10
IOL1: 8x1F-H8.5; 1X08
JP1: 3x2 M; 2X03
POWER1: 8x1F-H8.5; 1X08
R1: 1.0k; R0603
R2, R3: 3.3k; R0603
U1: SAMD21G18A-AUT; TQFP48
U$1, U$2, U$3, U$4, U$6, U$7, U$8, U$9, U$10, U$11, U$12, U$13, U$14, U$15, U$16, U$17, U$18, U$19, U$20, U$21, U$22, U$23, U$24, U$25, U$26, U$27, U$28, U$29, U$30, U$31: PAD
X1: 32.768kHz; FC-135

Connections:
+3V3: C1.1, C6.1, C7.1, C8.1, CN1.1, CN3.1, JP1.2, POWER1.2, POWER1.4, R1.2, R2.2, R3.2, U1.6 (VDDANA), U1.17 (VDDIO1), U1.36 (VDDIO2), U1.44 (VDDIN)
GND: C1.2, C2.2, C3.2, C4.1, C5.1, C6.2, C7.2, C8.2, C9.2, CN1.4, CN2.2, CN3.3, CN3.5, CN3.9, IOH1.7, JP1.6, POWER1.6, POWER1.7, U1.5 (GNDANA), U1.18 (GND1), U1.35 (GND2), U1.42 (GND3), U$2.1, U$8.1, U$9.1, U$10.1, U$11.1, U$12.1, U$13.1, U$14.1, U$15.1, U$16.1, U$17.1, U$18.1, U$19.1, U$20.1, U$21.1, U$22.1, U$23.1, U$24.1, U$25.1, U$26.1, U$27.1, U$28.1, U$31.1
MISO: IOH1.5, U1.28 (PA19/EIC/SCOM1PAD3+/TC3)
MOSI: IOH1.4, U1.25 (PA16/I2C/EIC/SCOM1PAD0+/TC2)
unnamed: POWER1.1, U$29.1
unnamed: POWER1.5, U$30.1
PA00_XIN32: C4.2, U1.1 (PA0/XIN32/EIC/SCOM1PAD0/TC2), X1.2
PA01_XOUT32: C5.2, U1.2 (PA1/XOUT32/EIC/SCOM1PAD1/TC2), X1.1
PA02_AIN0: AD1.1, U1.3 (PA2/EIC/AIN0)
PA03_AREFA: C9.1, IOH1.8, U1.4 (PA3/EIC/REF/AIN1)
PA04_AIN4: AD1.4, U1.9 (PA4/EIC/REF/AIN4/SCOM0PAD0/TC0)
PA05_AIN5: AD1.5, U1.10 (PA5/EIC/AIN5/SCOM0PAD1/TC0)
PA06: IOH1.1, U1.11 (PA6/EIC/AIN6/SCOM0PAD2/TC1)
PA07: IOH1.2, U1.12 (PA7/EIC/AIN7/SCOM0PAD3/TC1)
PA08_TCC0-W0: IOL1.3, U1.13 (PA8/I2C/AIN16/SCOM2PAD0+/TC0)
PA09_TCC0-W1: IOL1.4, U1.14 (PA9/I2C/EIC/AIN17/SCOM2PAD1+/TC0)
PA10_TCC0-W2: IOL1.2, U1.15 (PA10/EIC/AIN18/SCOM2PAD2+/TC1)
PA11_TCC0-W3: IOL1.1, U1.16 (PA11/EIC/AIN19/SCOM2PAD3+/TC1)
PA13_GPIO: CN1.5, R2.1, U1.22 (PA13/I2C/EIC/SCOM2PAD1+/TC2)
PA14_TCC0-W4: IOL1.5, U1.23 (PA14/XIN/EIC/SCOM2PAD2+/TC3)
PA15_TCC0-W5: IOL1.6, U1.24 (PA15/XOUT/EIC/SCOM2PAD3+/TC3)
PA20_TCC0-W6: IOL1.7, U1.29 (PA20/EIC/SCOM5PAD2+)
PA21: IOL1.8, U1.30 (PA21/EIC/SCOM5PAD3+)
PA27_TX_LED: U1.39 (PA27/EIC), U$4.1
PA28_USB_HOST_EN: U1.41 (PA28/EIC), U$3.1
PA30_SWCLK: CN3.4, R1.1, U1.45 (PA30/EIC/SCOM1PAD2/TC1)
PA31_SWDIO: CN3.2, U1.46 (PA31/EIC/SCOM1PAD3/TC1)
PB02_AIN10: AD1.6, U1.47 (PB2/EIC/AIN10/SCOM5PAD0)
PB03_RX_LED: U1.48 (PB3/EIC/AIN11/SCOM5PAD1), U$1.1
PB08_AIN2: AD1.2, U1.7 (PB8/EIC/AIN2/SCOM4PAD0/TC4)
PB09_AIN3: AD1.3, U1.8 (PB9/EIC/AIN3/SCOM4PAD1//TC4)
PB10_S4_SPI_MOSI: JP1.4, U1.19 (PB10/EIC/SCOM4PAD2/TC5)
PB11_S4_SPI_SCK: JP1.3, U1.20 (PB11/EIC/SCOM4PAD3/TC5)
PB12_S4_SPI_MISO: JP1.1, U1.21 (PA12/I2C/EIC/SCOM2PAD0+/TC2)
RXD: CN1.3, U1.38 (PB23/EIC/SCOM5PAD3)
SAMD21_RESET: C2.1, CN3.10, POWER1.3, R3.1, U1.40 (RESETN)
SCK: IOH1.6, U1.26 (PA17/I2C/EIC/SCOM1PAD1+/TC2)
SCL: IOH1.10, U1.32 (PA23/I2C/EIC/SCOM5PAD1+/TC4)
SDA: IOH1.9, U1.31 (PA22/I2C/EIC/SCOM5PAD0+/TC4)
SS: IOH1.3, U1.27 (PA18/EIC/SCOM1PAD2+/TC3)
TARGET_USB_N: U1.33 (PA24/EIC/SCOM3PAD2+/TC5), U$7.1
TARGET_USB_P: U1.34 (PA25/EIC/SCOM3PAD3+/TC5), U$6.1
TXD: CN1.2, U1.37 (PB22/EIC/SCOM5PAD2)
VDDCORE: C3.1, U1.43 (VDDCORE1)
VIN: CN2.1, POWER1.8

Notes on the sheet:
The ADC can measure a maximum of 2.7V when using an external reference
The AREF pin can use as highest external analog reference for the ADC

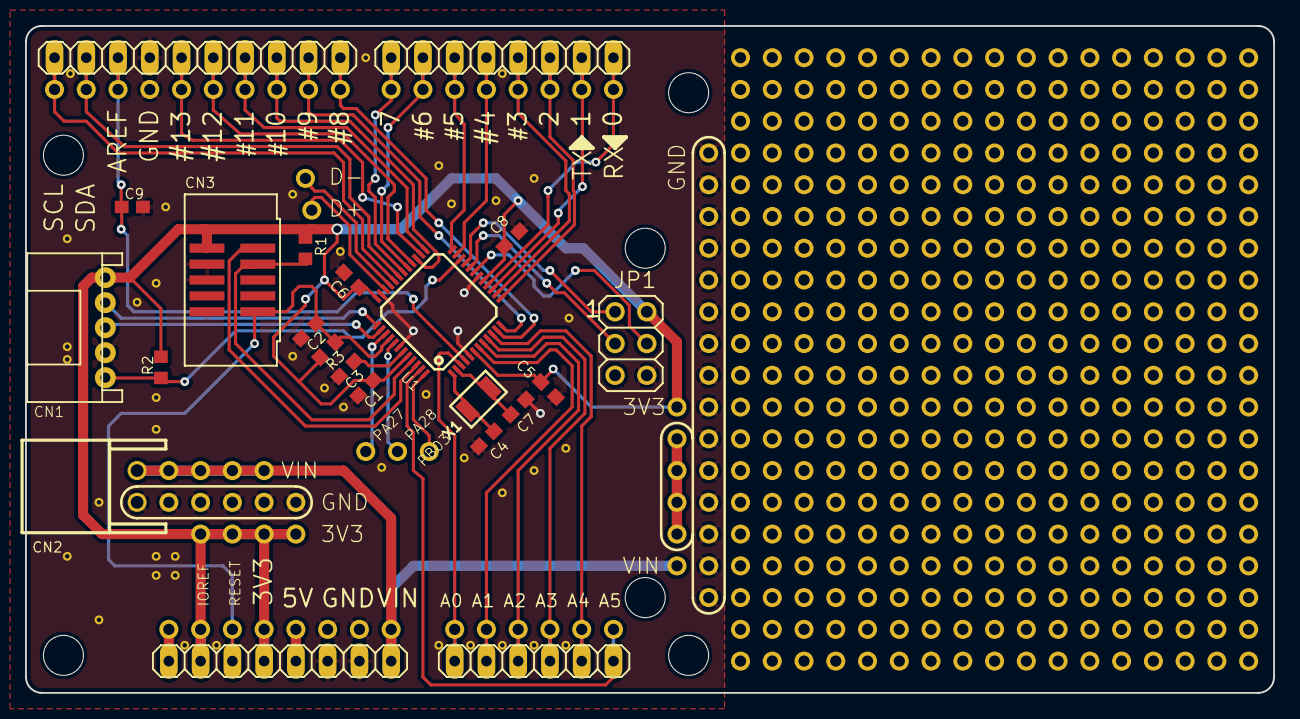
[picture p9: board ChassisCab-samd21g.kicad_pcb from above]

Board: 2 copper layers, 99.8 x 53.3 mm, 480 parts (0 on the bottom side), 45 nets.

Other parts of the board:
@HOLE1: @HOLE1
@HOLE2: @HOLE2
@HOLE3: @HOLE3
@HOLE4: @HOLE4
@HOLE5: @HOLE5
@HOLE6: @HOLE6
@V1: @V1
@V2: @V2
@V3: @V3
@V4: @V4
@V5: @V5
@V6: @V6
@V7: @V7
@V8: @V8
@V9: @V9
@V10: @V10
@V11: @V11
@V12: @V12
@V13: @V13
@V14: @V14
@V15: @V15
@V16: @V16
@V17: @V17
@V18: @V18
@V19: @V19
@V20: @V20
@V21: @V21
@V22: @V22
@V23: @V23
@V24: @V24
@V25: @V25
@V26: @V26
@V27: @V27
@V28: @V28
@V29: @V29
@V30: @V30
@V31: @V31
@V32: @V32
@V33: @V33
@V34: @V34
@V35: @V35
@V36: @V36
@V37: @V37
@V38: @V38
@V39: @V39
@V40: @V40
@V41: @V41
@V42: @V42
@V43: @V43
@V44: @V44
@V45: @V45
@V46: @V46
@V47: @V47
@V48: @V48
@V49: @V49
@V50: @V50
@V51: @V51
@V52: @V52
@V53: @V53
@V54: @V54
@V55: @V55
@V56: @V56
@V57: @V57
@V58: @V58
@V59: @V59
@V60: @V60
@V61: @V61
@V62: @V62
@V63: @V63
@V64: @V64
@V65: @V65
@V66: @V66
@V67: @V67
@V68: @V68
@V69: @V69
@V70: @V70
@V71: @V71
@V72: @V72
@V73: @V73
@V74: @V74
@V75: @V75
@V76: @V76
@V77: @V77
@V78: @V78
@V79: @V79
@V80: @V80
@V81: @V81
@V82: @V82
@V83: @V83
@V84: @V84
@V85: @V85
@V86: @V86
@V87: @V87
@V88: @V88
@V89: @V89
@V90: @V90
@V91: @V91
@V92: @V92
@V93: @V93
@V94: @V94
@V95: @V95
@V96: @V96
@V97: @V97
@V98: @V98
@V99: @V99
@V100: @V100
@V101: @V101
@V102: @V102
@V103: @V103
@V104: @V104
@V105: @V105
@V106: @V106
@V107: @V107
@V108: @V108
@V109: @V109
@V110: @V110
@V111: @V111
@V112: @V112
@V113: @V113
@V114: @V114
@V115: @V115
@V116: @V116
@V117: @V117
@V118: @V118
@V119: @V119
@V120: @V120
@V121: @V121
@V122: @V122
@V123: @V123
@V124: @V124
@V125: @V125
@V126: @V126
@V127: @V127
@V128: @V128
@V129: @V129
@V130: @V130
@V131: @V131
@V132: @V132
@V133: @V133
@V134: @V134
@V135: @V135
@V136: @V136
@V137: @V137
@V138: @V138
@V139: @V139
@V140: @V140
@V141: @V141
@V142: @V142
@V143: @V143
@V144: @V144
@V145: @V145
@V146: @V146
@V147: @V147
@V148: @V148
@V149: @V149
@V150: @V150
@V151: @V151
@V152: @V152
@V153: @V153
@V154: @V154
@V155: @V155
@V156: @V156
@V157: @V157
@V158: @V158
@V159: @V159
@V160: @V160
@V161: @V161
@V162: @V162
@V163: @V163
@V164: @V164
@V165: @V165
@V166: @V166
@V167: @V167
@V168: @V168
@V169: @V169
@V170: @V170
@V171: @V171
@V172: @V172
@V173: @V173
@V174: @V174
@V175: @V175
@V176: @V176
@V177: @V177
@V178: @V178
@V179: @V179
@V180: @V180
@V181: @V181
@V182: @V182
@V183: @V183
@V184: @V184
@V185: @V185
@V186: @V186
@V187: @V187
@V188: @V188
@V189: @V189
@V190: @V190
@V191: @V191
@V192: @V192
@V193: @V193
@V194: @V194
@V195: @V195
@V196: @V196
@V197: @V197
@V198: @V198
@V199: @V199
@V200: @V200
@V201: @V201
@V202: @V202
@V203: @V203
@V204: @V204
@V205: @V205
@V206: @V206
@V207: @V207
@V208: @V208
@V209: @V209
@V210: @V210
@V211: @V211
@V212: @V212
@V213: @V213
@V214: @V214
@V215: @V215
@V216: @V216
@V217: @V217
@V218: @V218
@V219: @V219
@V220: @V220
@V221: @V221
@V222: @V222
@V223: @V223
@V224: @V224
@V225: @V225
@V226: @V226
@V227: @V227
@V228: @V228
@V229: @V229
@V230: @V230
@V231: @V231
@V232: @V232
@V233: @V233
@V234: @V234
@V235: @V235
@V236: @V236
@V237: @V237
@V238: @V238
@V239: @V239
@V240: @V240
@V241: @V241
@V242: @V242
@V243: @V243
@V244: @V244
@V245: @V245
@V246: @V246
@V247: @V247
@V248: @V248
@V249: @V249
@V250: @V250
@V251: @V251
@V252: @V252
@V253: @V253
@V254: @V254
@V255: @V255
@V256: @V256
@V257: @V257
@V258: @V258
@V259: @V259
@V260: @V260
@V261: @V261
@V262: @V262
@V263: @V263
@V264: @V264
@V265: @V265
@V266: @V266
@V267: @V267
@V268: @V268
@V269: @V269
@V270: @V270
@V271: @V271
@V272: @V272
@V273: @V273
@V274: @V274
@V275: @V275
@V276: @V276
@V277: @V277
@V278: @V278
@V279: @V279
@V280: @V280
@V281: @V281
@V282: @V282
@V283: @V283
@V284: @V284
@V285: @V285
@V286: @V286
@V287: @V287
@V288: @V288
@V289: @V289
@V290: @V290
@V291: @V291
@V292: @V292
@V293: @V293
@V294: @V294
@V295: @V295
@V296: @V296
@V297: @V297
@V298: @V298
@V299: @V299
@V300: @V300
@V301: @V301
@V302: @V302
@V303: @V303
@V304: @V304
@V305: @V305
@V306: @V306
@V307: @V307
@V308: @V308
@V309: @V309
@V310: @V310
@V311: @V311
@V312: @V312
@V313: @V313
@V314: @V314
@V315: @V315
@V316: @V316
@V317: @V317
@V318: @V318
@V319: @V319
@V320: @V320
@V321: @V321
@V322: @V322
@V323: @V323
@V324: @V324
@V325: @V325
@V326: @V326
@V327: @V327
@V328: @V328
@V329: @V329
@V330: @V330
@V331: @V331
@V332: @V332
@V333: @V333
@V334: @V334
@V335: @V335
@V336: @V336
@V337: @V337
@V338: @V338
@V339: @V339
@V340: @V340
@V341: @V341
@V342: @V342
@V343: @V343
@V344: @V344
@V345: @V345
@V346: @V346
@V347: @V347
@V348: @V348
@V349: @V349
@V350: @V350
@V351: @V351
@V352: @V352
@V353: @V353
@V354: @V354
@V355: @V355
@V356: @V356
@V357: @V357
@V358: @V358
@V359: @V359
@V360: @V360
@V361: @V361
@V362: @V362
@V363: @V363
@V364: @V364
@V365: @V365
@V366: @V366
@V367: @V367
@V368: @V368
@V369: @V369
@V370: @V370
@V371: @V371
@V372: @V372
@V373: @V373
@V374: @V374
@V375: @V375
@V376: @V376
@V377: @V377
@V378: @V378
@V379: @V379
@V380: @V380
@V381: @V381
@V382: @V382
@V383: @V383
@V384: @V384
@V385: @V385
@V386: @V386
@V387: @V387
@V388: @V388
@V389: @V389
@V390: @V390
@V391: @V391
@V392: @V392
@V393: @V393
@V394: @V394
@V395: @V395
@V396: @V396
@V397: @V397
@V398: @V398
@V399: @V399
@V400: @V400
@V401: @V401
@V402: @V402
@V403: @V403
@V404: @V404
@V405: @V405
@V406: @V406
@V407: @V407
@V408: @V408
@V409: @V409
@V410: @V410
@V411: @V411
@V412: @V412
@V413: @V413
@V414: @V414
@V415: @V415
@V416: @V416
@V417: @V417
@V418: @V418
@V419: @V419
@V420: @V420
@V421: @V421
@V422: @V422

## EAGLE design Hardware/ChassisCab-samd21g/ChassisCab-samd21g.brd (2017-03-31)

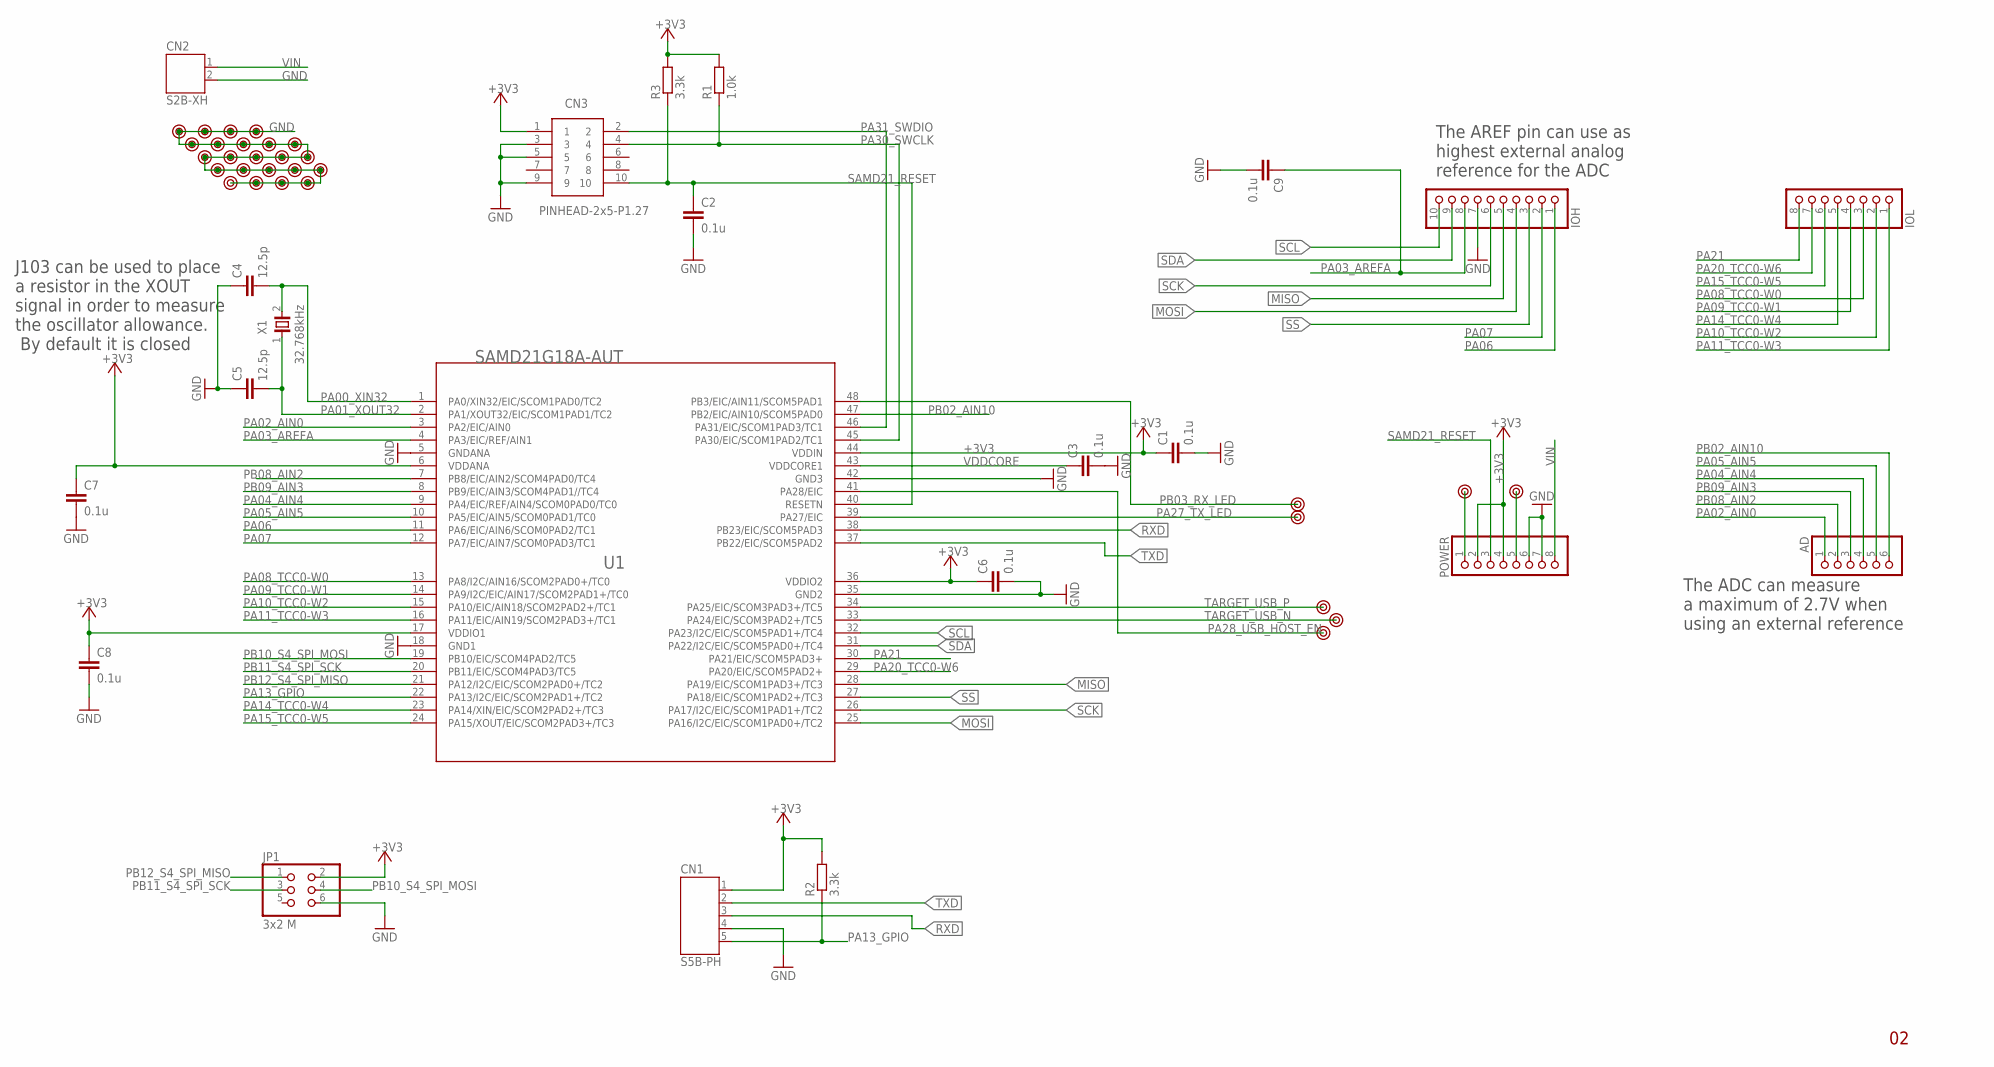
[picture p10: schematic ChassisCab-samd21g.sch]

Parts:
AD: 6x1F-H8.5; 1X06
C1, C2, C3, C6, C7, C8, C9: 0.1u; C0603
C4, C5: 12.5p; C0603
CN1: S5B-PH
CN2: S2B-XH
CN3: PINHEAD-2x5-P1.27; SHF-105-01-X-D-SM
IOH: 10x1F-H8.5; 1X10
IOL: 8x1F-H8.5; 1X08
JP1: 3x2 M; 2X03
POWER: 8x1F-H8.5; 1X08
R1: 1.0k; R0603
R2, R3: 3.3k; R0603
U1: SAMD21G18A-AUT; TQFP48
U$1, U$2, U$3, U$4, U$6, U$7, U$8, U$9, U$10, U$11, U$12, U$13, U$14, U$15, U$16, U$17, U$18, U$19, U$20, U$21, U$22, U$23, U$24, U$25, U$26, U$27, U$28, U$29, U$30, U$31: PAD
X1: 32.768kHz; FC-135

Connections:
+3V3: C1.1, C6.1, C7.1, C8.1, CN1.1, CN3.1, JP1.2, POWER.2, POWER.4, R1.2, R2.2, R3.2, U1.6 (VDDANA), U1.17 (VDDIO1), U1.36 (VDDIO2), U1.44 (VDDIN)
GND: C1.2, C2.2, C3.2, C4.1, C5.1, C6.2, C7.2, C8.2, C9.2, CN1.4, CN2.2, CN3.3, CN3.5, CN3.9, IOH.7, JP1.6, POWER.6, POWER.7, U1.5 (GNDANA), U1.18 (GND1), U1.35 (GND2), U1.42 (GND3), U$2.1, U$8.1, U$9.1, U$10.1, U$11.1, U$12.1, U$13.1, U$14.1, U$15.1, U$16.1, U$17.1, U$18.1, U$19.1, U$20.1, U$21.1, U$22.1, U$23.1, U$24.1, U$25.1, U$26.1, U$27.1, U$28.1, U$31.1
MISO: IOH.5, U1.28 (PA19/EIC/SCOM1PAD3+/TC3)
MOSI: IOH.4, U1.25 (PA16/I2C/EIC/SCOM1PAD0+/TC2)
unnamed: POWER.1, U$29.1
unnamed: POWER.5, U$30.1
PA00_XIN32: C4.2, U1.1 (PA0/XIN32/EIC/SCOM1PAD0/TC2), X1.2
PA01_XOUT32: C5.2, U1.2 (PA1/XOUT32/EIC/SCOM1PAD1/TC2), X1.1
PA02_AIN0: AD.1, U1.3 (PA2/EIC/AIN0)
PA03_AREFA: C9.1, IOH.8, U1.4 (PA3/EIC/REF/AIN1)
PA04_AIN4: AD.4, U1.9 (PA4/EIC/REF/AIN4/SCOM0PAD0/TC0)
PA05_AIN5: AD.5, U1.10 (PA5/EIC/AIN5/SCOM0PAD1/TC0)
PA06: IOH.1, U1.11 (PA6/EIC/AIN6/SCOM0PAD2/TC1)
PA07: IOH.2, U1.12 (PA7/EIC/AIN7/SCOM0PAD3/TC1)
PA08_TCC0-W0: IOL.3, U1.13 (PA8/I2C/AIN16/SCOM2PAD0+/TC0)
PA09_TCC0-W1: IOL.4, U1.14 (PA9/I2C/EIC/AIN17/SCOM2PAD1+/TC0)
PA10_TCC0-W2: IOL.2, U1.15 (PA10/EIC/AIN18/SCOM2PAD2+/TC1)
PA11_TCC0-W3: IOL.1, U1.16 (PA11/EIC/AIN19/SCOM2PAD3+/TC1)
PA13_GPIO: CN1.5, R2.1, U1.22 (PA13/I2C/EIC/SCOM2PAD1+/TC2)
PA14_TCC0-W4: IOL.5, U1.23 (PA14/XIN/EIC/SCOM2PAD2+/TC3)
PA15_TCC0-W5: IOL.6, U1.24 (PA15/XOUT/EIC/SCOM2PAD3+/TC3)
PA20_TCC0-W6: IOL.7, U1.29 (PA20/EIC/SCOM5PAD2+)
PA21: IOL.8, U1.30 (PA21/EIC/SCOM5PAD3+)
PA27_TX_LED: U1.39 (PA27/EIC), U$4.1
PA28_USB_HOST_EN: U1.41 (PA28/EIC), U$3.1
PA30_SWCLK: CN3.4, R1.1, U1.45 (PA30/EIC/SCOM1PAD2/TC1)
PA31_SWDIO: CN3.2, U1.46 (PA31/EIC/SCOM1PAD3/TC1)
PB02_AIN10: AD.6, U1.47 (PB2/EIC/AIN10/SCOM5PAD0)
PB03_RX_LED: U1.48 (PB3/EIC/AIN11/SCOM5PAD1), U$1.1
PB08_AIN2: AD.2, U1.7 (PB8/EIC/AIN2/SCOM4PAD0/TC4)
PB09_AIN3: AD.3, U1.8 (PB9/EIC/AIN3/SCOM4PAD1//TC4)
PB10_S4_SPI_MOSI: JP1.4, U1.19 (PB10/EIC/SCOM4PAD2/TC5)
PB11_S4_SPI_SCK: JP1.3, U1.20 (PB11/EIC/SCOM4PAD3/TC5)
PB12_S4_SPI_MISO: JP1.1, U1.21 (PA12/I2C/EIC/SCOM2PAD0+/TC2)
RXD: CN1.3, U1.38 (PB23/EIC/SCOM5PAD3)
SAMD21_RESET: C2.1, CN3.10, POWER.3, R3.1, U1.40 (RESETN)
SCK: IOH.6, U1.26 (PA17/I2C/EIC/SCOM1PAD1+/TC2)
SCL: IOH.10, U1.32 (PA23/I2C/EIC/SCOM5PAD1+/TC4)
SDA: IOH.9, U1.31 (PA22/I2C/EIC/SCOM5PAD0+/TC4)
SS: IOH.3, U1.27 (PA18/EIC/SCOM1PAD2+/TC3)
TARGET_USB_N: U1.33 (PA24/EIC/SCOM3PAD2+/TC5), U$7.1
TARGET_USB_P: U1.34 (PA25/EIC/SCOM3PAD3+/TC5), U$6.1
TXD: CN1.2, U1.37 (PB22/EIC/SCOM5PAD2)
VDDCORE: C3.1, U1.43 (VDDCORE1)
VIN: CN2.1, POWER.8

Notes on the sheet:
J103 can be used to place a resistor in the XOUT signal in order to measure the oscillator allowance. By default it is closed
The ADC can measure a maximum of 2.7V when using an external reference
The AREF pin can use as highest external analog reference for the ADC

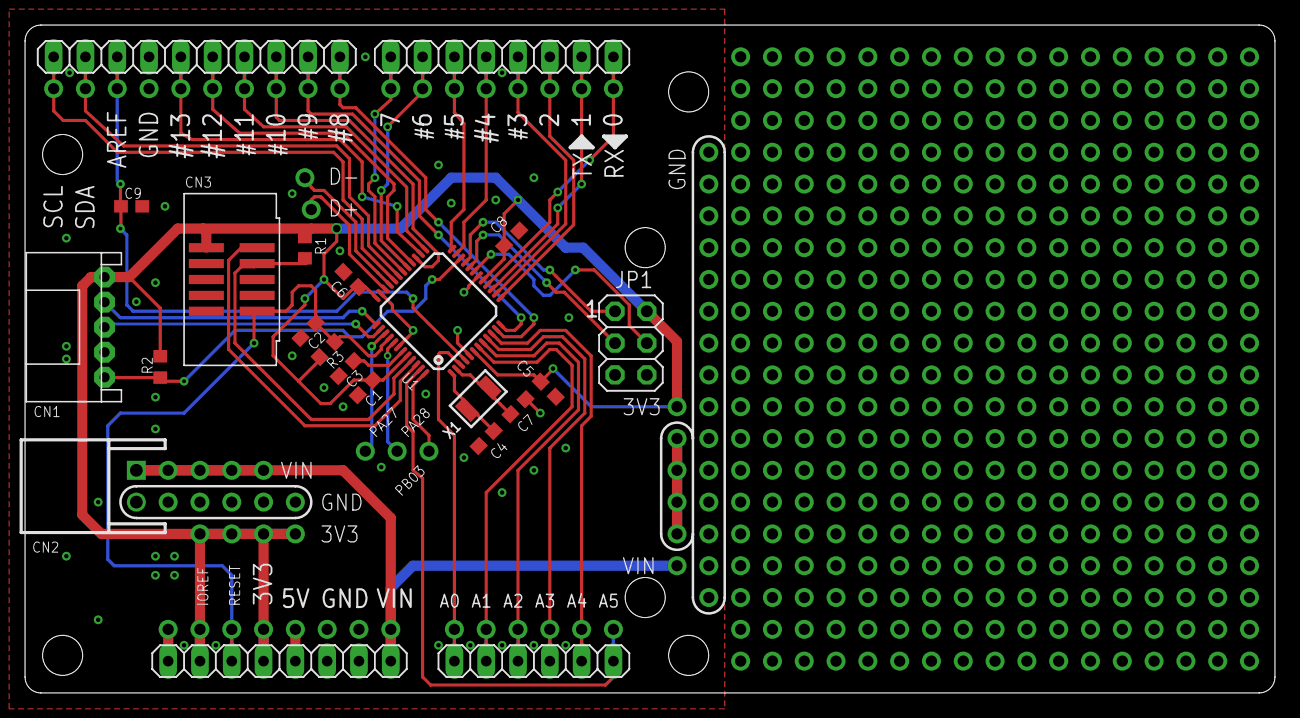
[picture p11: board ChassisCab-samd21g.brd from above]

Board: 2 copper layers, 99.8 x 53.3 mm, 52 parts (0 on the bottom side), 45 nets.

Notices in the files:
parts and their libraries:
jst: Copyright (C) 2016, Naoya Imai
